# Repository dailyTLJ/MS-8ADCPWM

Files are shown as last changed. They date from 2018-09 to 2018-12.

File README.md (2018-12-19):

# MS_8ADCPWM

Board with 2x ADS8688a chips (8 analog inputs each) and 1x TLC5947 chip (24ch LED PWM driver).

Issues when chaining more than 4 boards (8 ADS8688a ics)

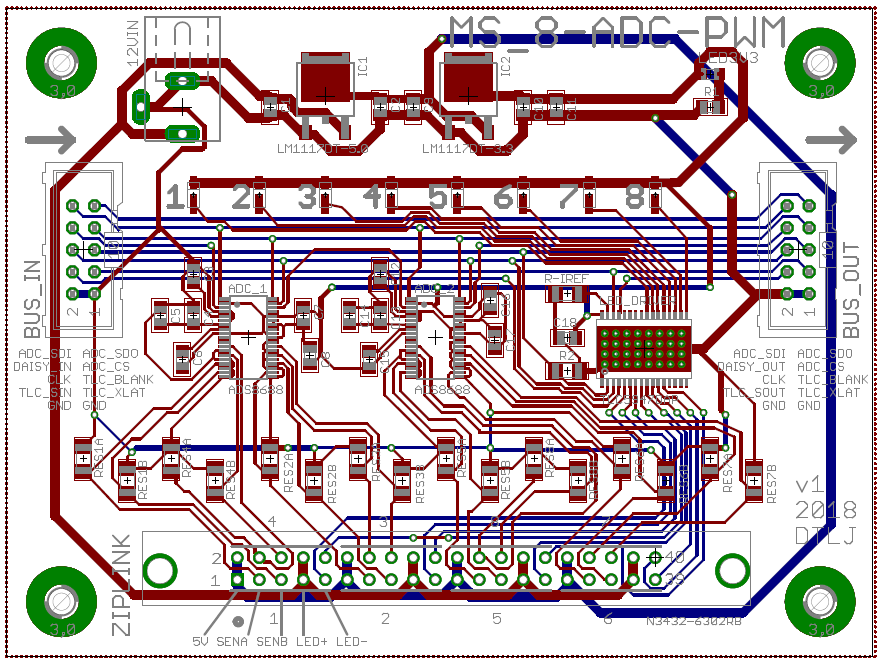
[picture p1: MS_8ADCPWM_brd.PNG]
Board


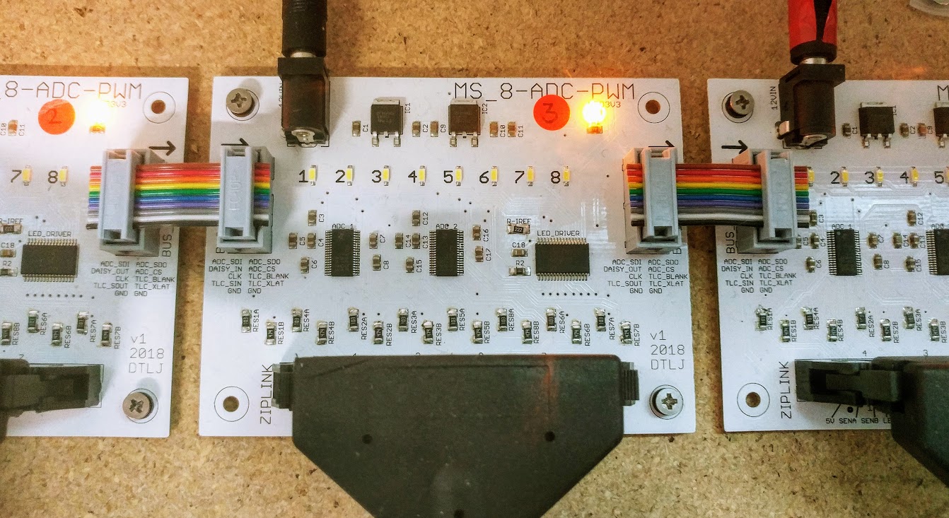
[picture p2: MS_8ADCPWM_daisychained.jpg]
In Action


## next iteration

* digital buffers, to allow larger chains
* default-off on LED channels, in the absence of control signal 
* power-in with screw terminals?

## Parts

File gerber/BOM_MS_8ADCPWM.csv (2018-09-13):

Designator | Manufacturer Part Number | Quantity
ADC_1, ADC_2 | ADS8688IDBT | 2
LED_DRIVER | TLC5947DAPR | 1
IC1 | LM1117IDTX-5.0/NOPB | 1
IC2 | LM1117IDTX-3.3/NOPB | 1
LED1B, LED2B, LED3B, LED4B, LED5B, LED6B, LED7B, LED8B | QBLP674-IWM-CW | 8
LED3V3 | LTST-C170EKT | 1
R1 | RC0805JR-07130RL | 1
R2 | RC0805FR-0710KL | 1
C9, C10, C18 | CL21F104ZBCNNNC | 3
C4, C6, C7, C13, C15, C16 | CL21B105KBFNNNE | 6
C1, C2, C3, C8, C12, C17 | CL21A106KPCLQNC | 6
C5, C11, C14 | CL21A226MQCLQNC | 3

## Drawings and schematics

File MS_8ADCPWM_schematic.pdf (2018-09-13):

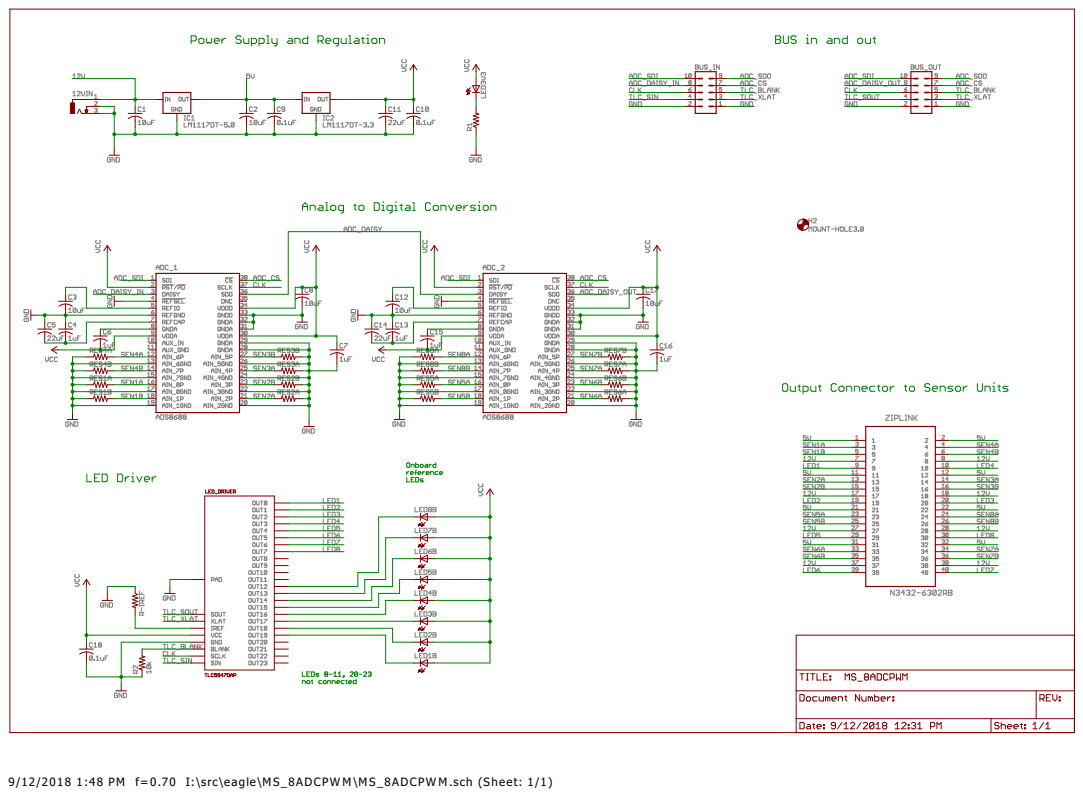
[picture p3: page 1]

9/12/2018 1:48 PM f=0.70 I:\src\eagle\MS_8ADCPW M\MS_8ADCPW M.sch (Sheet: 1/1)

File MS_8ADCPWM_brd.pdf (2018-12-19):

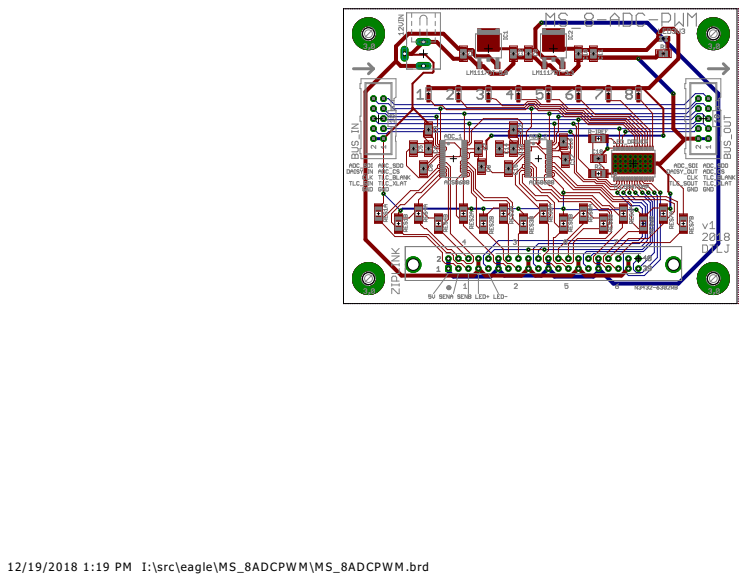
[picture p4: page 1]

12/19/2018 1:19 PM I:\src\eagle\MS_8ADCPW M\MS_8ADCPW M.brd

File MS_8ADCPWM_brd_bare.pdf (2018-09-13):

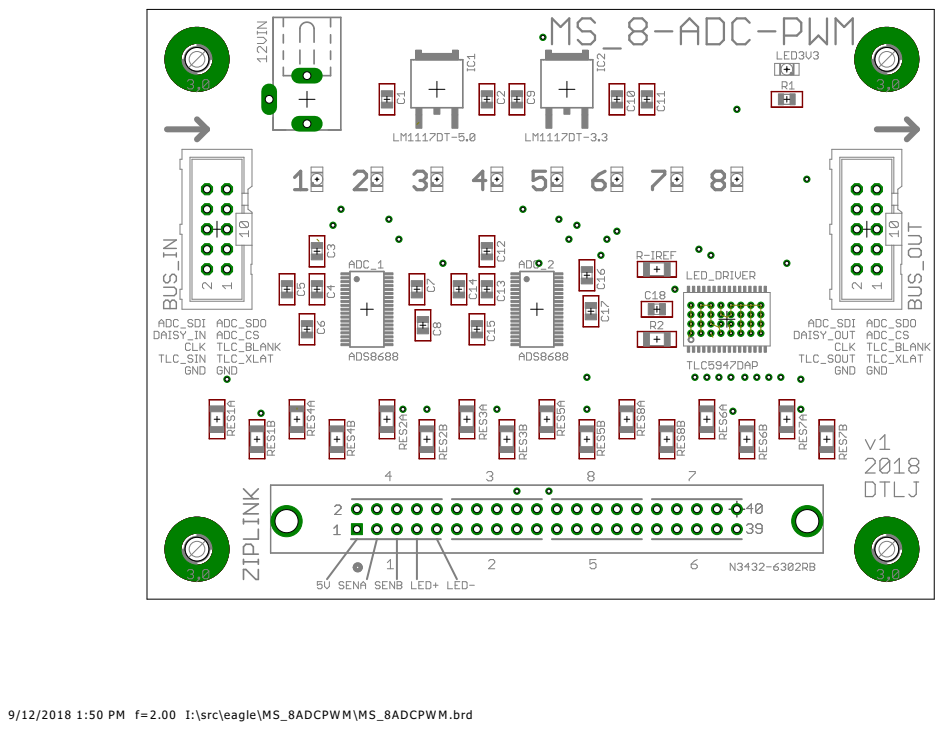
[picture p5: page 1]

9/12/2018 1:50 PM f=2.00 I:\src\eagle\MS_8ADCPW M\MS_8ADCPW M.brd

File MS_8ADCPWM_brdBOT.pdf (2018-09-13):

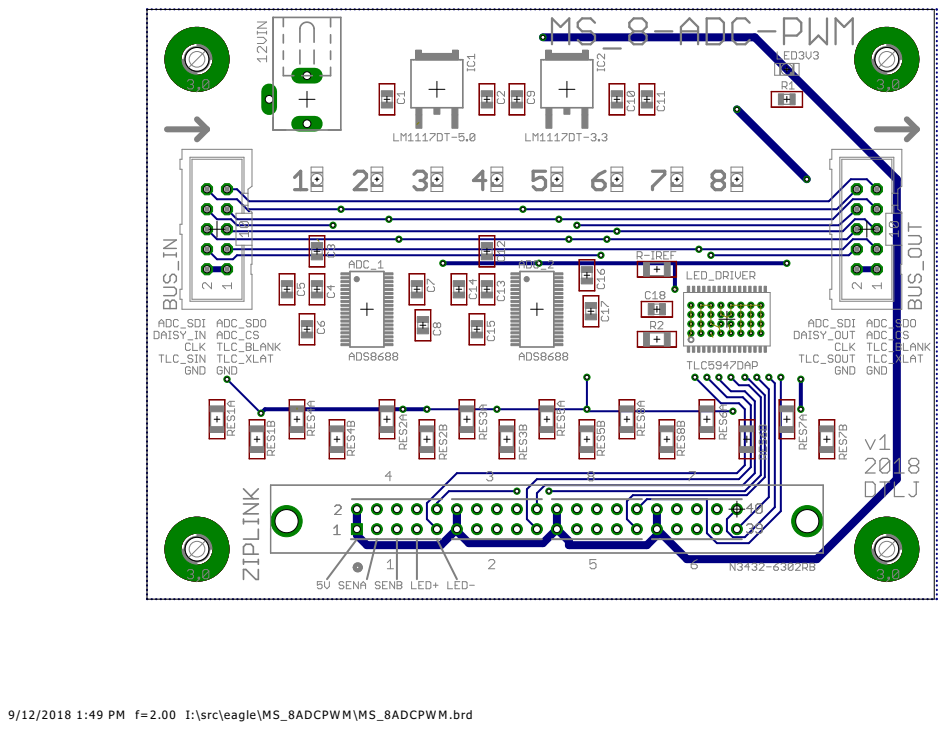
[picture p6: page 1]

9/12/2018 1:49 PM f=2.00 I:\src\eagle\MS_8ADCPW M\MS_8ADCPW M.brd

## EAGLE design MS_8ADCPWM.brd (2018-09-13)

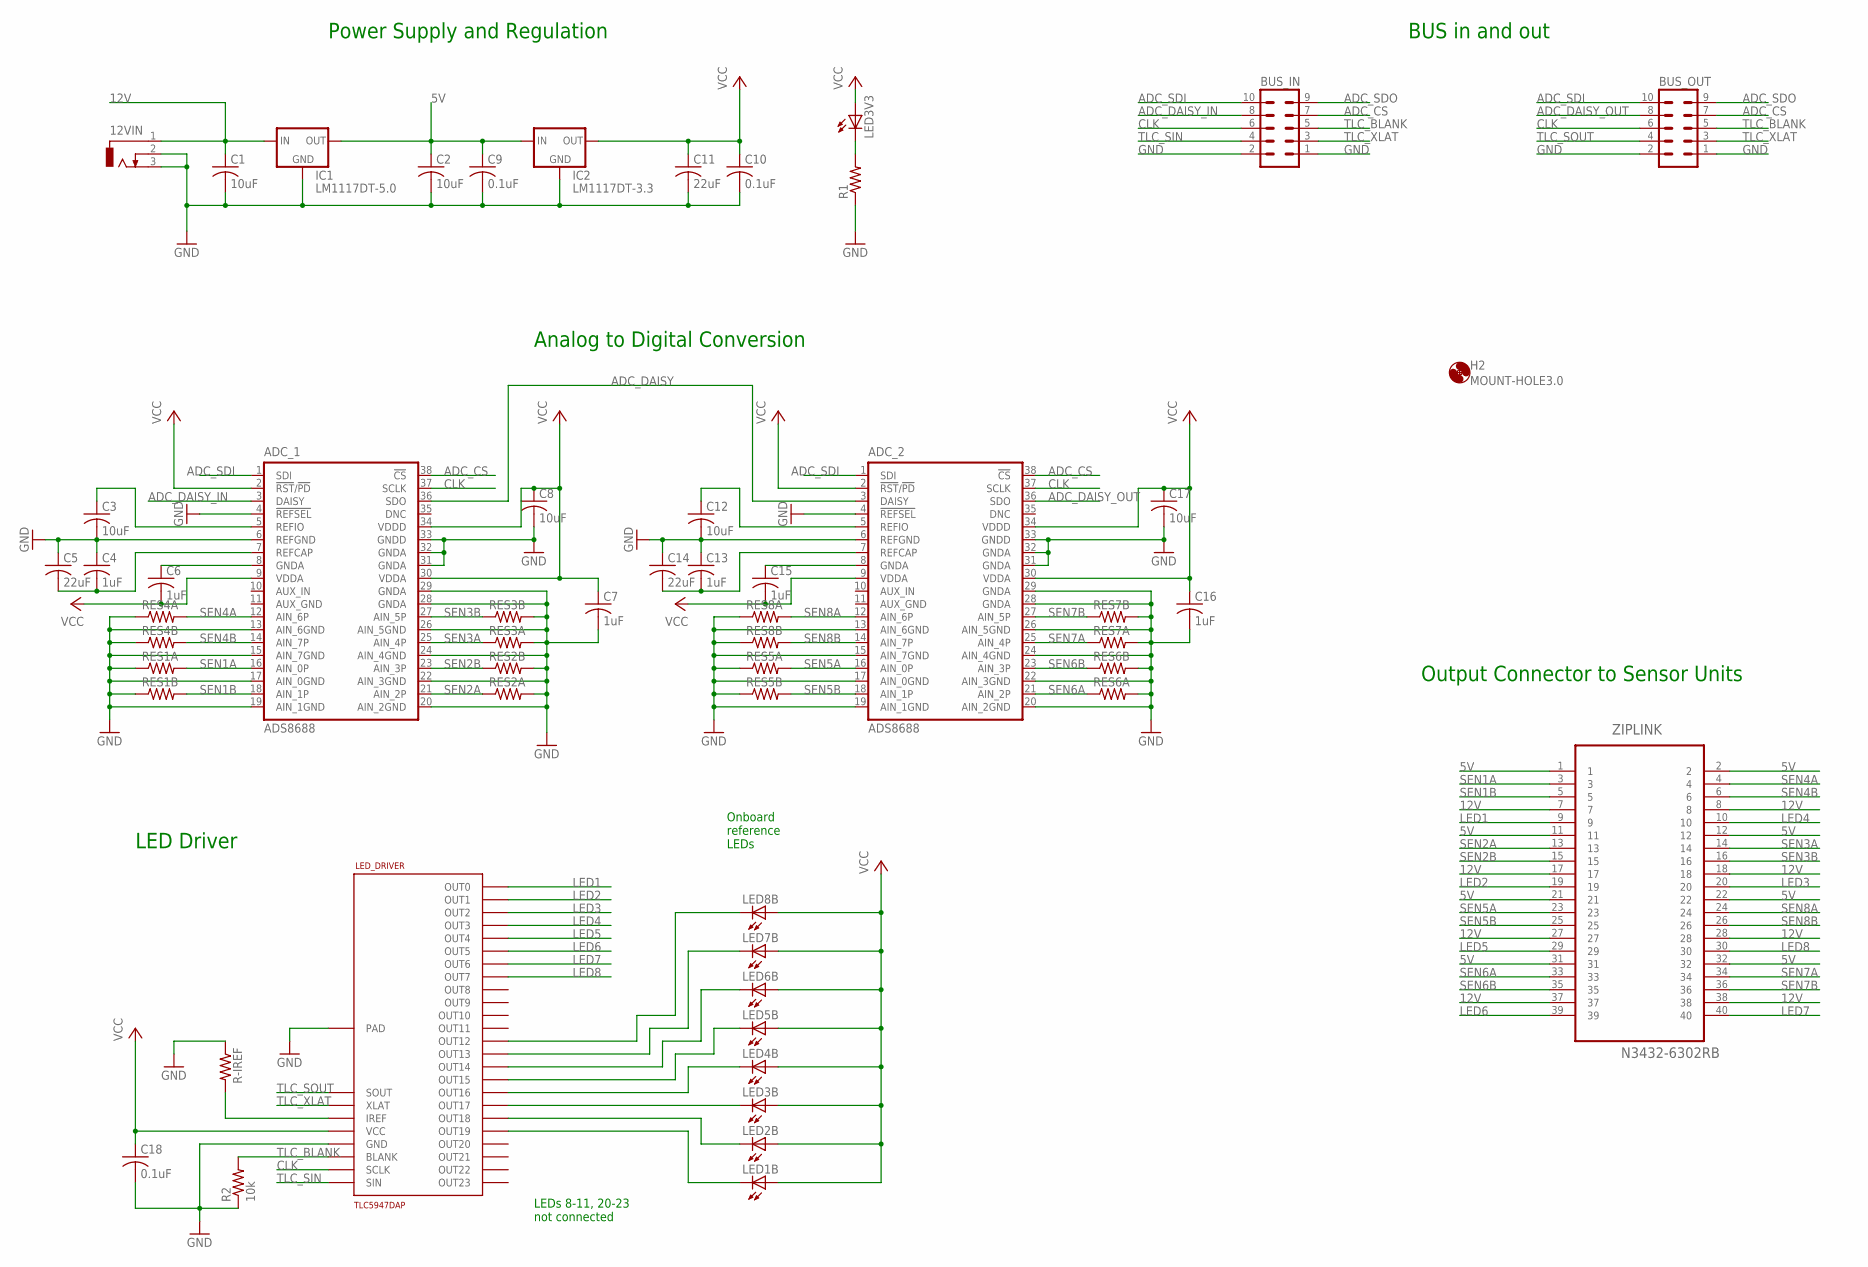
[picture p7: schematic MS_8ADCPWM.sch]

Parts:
12VIN: DCJ0303
ADC_1, ADC_2: ADS8688; DBT_R-PDSO-G38
BUS_IN: ML10
BUS_OUT: ML10
C1, C2, C3, C8, C12, C17: 10uF; C0805
C4, C6, C7, C13, C15, C16: 1uF; C0805
C5, C11, C14: 22uF; C0805
C9, C10, C18: 0.1uF; C0805
H2: MOUNT-HOLE3.0; 3,0
IC1: LM1117DT-5.0; TO252
IC2: LM1117DT-3.3; TO252
LED1B, LED2B, LED3B, LED4B, LED5B, LED6B, LED7B, LED8B: LEDSMD2PLCC; 2-PLCC
LED3V3: LEDCHIPLED_0805; CHIPLED_0805
LED_DRIVER: TLC5947DAP; HTSSOP32DAP
R1: R-US_R0805; R0805
R2: 10k; R1206
R-IREF: R-US_R1206; R1206
RES1A, RES1B, RES2A, RES2B, RES3A, RES3B, RES4A, RES4B, RES5A, RES5B, RES6A, RES6B, RES7A, RES7B, RES8A, RES8B: R-US_R1206; R1206
ZIPLINK: N3432-6302RB; 3M_N3432-6302RB

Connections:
5V: C2.1, C9.1, IC1.3 (OUT), IC2.2 (IN), ZIPLINK.1, ZIPLINK.2, ZIPLINK.11, ZIPLINK.12, ZIPLINK.21, ZIPLINK.22, ZIPLINK.31, ZIPLINK.32
12V: 12VIN.1, C1.1, IC1.2 (IN), ZIPLINK.7, ZIPLINK.8, ZIPLINK.17, ZIPLINK.18, ZIPLINK.27, ZIPLINK.28, ZIPLINK.37, ZIPLINK.38
ADC_CS: ADC_1.38 (!CS), ADC_2.38 (!CS), BUS_IN.7, BUS_OUT.7
ADC_DAISY: ADC_1.36 (SDO), ADC_2.3 (DAISY)
ADC_DAISY_IN: ADC_1.3 (DAISY), BUS_IN.8
ADC_DAISY_OUT: ADC_2.36 (SDO), BUS_OUT.8
ADC_SDI: ADC_1.1 (SDI), ADC_2.1 (SDI), BUS_IN.10, BUS_OUT.10
ADC_SDO: BUS_IN.9, BUS_OUT.9
CLK: ADC_1.37 (SCLK), ADC_2.37 (SCLK), BUS_IN.6, BUS_OUT.6, LED_DRIVER.3 (SCLK)
GND: 12VIN.2, 12VIN.3, ADC_1.4 (!REFSEL), ADC_1.6 (REFGND), ADC_1.13 (AIN_6GND), ADC_1.15 (AIN_7GND), ADC_1.17 (AIN_0GND), ADC_1.19 (AIN_1GND), ADC_1.20 (AIN_2GND), ADC_1.22 (AIN_3GND), ADC_1.24 (AIN_4GND), ADC_1.26 (AIN_5GND), ADC_1.28 (GNDA), ADC_1.29 (GNDA), ADC_1.31 (GNDA), ADC_1.32 (GNDA), ADC_1.33 (GNDD), ADC_2.4 (!REFSEL), ADC_2.6 (REFGND), ADC_2.13 (AIN_6GND), ADC_2.15 (AIN_7GND), ADC_2.17 (AIN_0GND), ADC_2.19 (AIN_1GND), ADC_2.20 (AIN_2GND), ADC_2.22 (AIN_3GND), ADC_2.24 (AIN_4GND), ADC_2.26 (AIN_5GND), ADC_2.28 (GNDA), ADC_2.29 (GNDA), ADC_2.31 (GNDA), ADC_2.32 (GNDA), ADC_2.33 (GNDD), BUS_IN.1, BUS_IN.2, BUS_OUT.1, BUS_OUT.2, C1.2, C2.2, C3.2, C4.1, C5.1, C7.2, C8.2, C9.2, C10.2, C11.2, C12.2, C13.1, C14.1, C16.2, C17.2, C18.2, IC1.1 (GND), IC2.1 (GND), LED_DRIVER.1 (GND), LED_DRIVER.EXP (PAD), R1.1, R2.1, R-IREF.1, RES1A.1, RES1B.1, RES2A.2, RES2B.2, RES3A.2, RES3B.2, RES4A.1, RES4B.1, RES5A.1, RES5B.1, RES6A.2, RES6B.2, RES7A.2, RES7B.2, RES8A.1, RES8B.1
LED1: LED_DRIVER.5 (OUT0), ZIPLINK.9
LED2: LED_DRIVER.6 (OUT1), ZIPLINK.19
LED3: LED_DRIVER.7 (OUT2), ZIPLINK.20
LED4: LED_DRIVER.8 (OUT3), ZIPLINK.10
LED5: LED_DRIVER.9 (OUT4), ZIPLINK.29
LED6: LED_DRIVER.10 (OUT5), ZIPLINK.39
LED7: LED_DRIVER.11 (OUT6), ZIPLINK.40
LED8: LED_DRIVER.12 (OUT7), ZIPLINK.30
unnamed: ADC_1.5 (REFIO), C3.1
unnamed: LED3V3.C, R1.2
unnamed: ADC_2.7 (REFCAP), C13.2, C14.2
unnamed: ADC_1.7 (REFCAP), C4.2, C5.2
unnamed: ADC_2.5 (REFIO), C12.1
unnamed: ADC_2.8 (GNDA), C15.1
unnamed: ADC_1.8 (GNDA), C6.1
unnamed: LED1B.C, LED_DRIVER.24 (OUT19)
unnamed: LED_DRIVER.31 (IREF), R-IREF.2
unnamed: LED2B.C, LED_DRIVER.23 (OUT18)
unnamed: LED3B.C, LED_DRIVER.22 (OUT17)
unnamed: LED4B.C, LED_DRIVER.21 (OUT16)
unnamed: LED5B.C, LED_DRIVER.20 (OUT15)
unnamed: LED6B.C, LED_DRIVER.19 (OUT14)
unnamed: LED7B.C, LED_DRIVER.18 (OUT13)
unnamed: LED8B.C, LED_DRIVER.17 (OUT12)
SEN1A: ADC_1.16 (AIN_0P), RES1A.2, ZIPLINK.3
SEN1B: ADC_1.18 (AIN_1P), RES1B.2, ZIPLINK.5
SEN2A: ADC_1.21 (AIN_2P), RES2A.1, ZIPLINK.13
SEN2B: ADC_1.23 (AIN_3P), RES2B.1, ZIPLINK.15
SEN3A: ADC_1.25 (AIN_4P), RES3A.1, ZIPLINK.14
SEN3B: ADC_1.27 (AIN_5P), RES3B.1, ZIPLINK.16
SEN4A: ADC_1.12 (AIN_6P), RES4A.2, ZIPLINK.4
SEN4B: ADC_1.14 (AIN_7P), RES4B.2, ZIPLINK.6
SEN5A: ADC_2.16 (AIN_0P), RES5A.2, ZIPLINK.23
SEN5B: ADC_2.18 (AIN_1P), RES5B.2, ZIPLINK.25
SEN6A: ADC_2.21 (AIN_2P), RES6A.1, ZIPLINK.33
SEN6B: ADC_2.23 (AIN_3P), RES6B.1, ZIPLINK.35
SEN7A: ADC_2.25 (AIN_4P), RES7A.1, ZIPLINK.34
SEN7B: ADC_2.27 (AIN_5P), RES7B.1, ZIPLINK.36
SEN8A: ADC_2.12 (AIN_6P), RES8A.2, ZIPLINK.24
SEN8B: ADC_2.14 (AIN_7P), RES8B.2, ZIPLINK.26
TLC_BLANK: BUS_IN.5, BUS_OUT.5, LED_DRIVER.2 (BLANK), R2.2
TLC_SIN: BUS_IN.4, LED_DRIVER.4 (SIN)
TLC_SOUT: BUS_OUT.4, LED_DRIVER.29 (SOUT)
TLC_XLAT: BUS_IN.3, BUS_OUT.3, LED_DRIVER.30 (XLAT)
VCC: ADC_1.2 (!RST!/!PD), ADC_1.9 (VDDA), ADC_1.30 (VDDA), ADC_1.34 (VDDD), ADC_2.2 (!RST!/!PD), ADC_2.9 (VDDA), ADC_2.30 (VDDA), ADC_2.34 (VDDD), C6.2, C7.1, C8.1, C10.1, C11.1, C15.2, C16.1, C17.1, C18.1, IC2.3 (OUT), LED1B.A, LED2B.A, LED3B.A, LED3V3.A, LED4B.A, LED5B.A, LED6B.A, LED7B.A, LED8B.A, LED_DRIVER.32 (VCC)

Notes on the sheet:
Power Supply and Regulation
Analog to Digital Conversion
LED Driver
Output Connector to Sensor Units
BUS in and out
Onboard reference LEDs
LEDs 8-11, 20-23 not connected

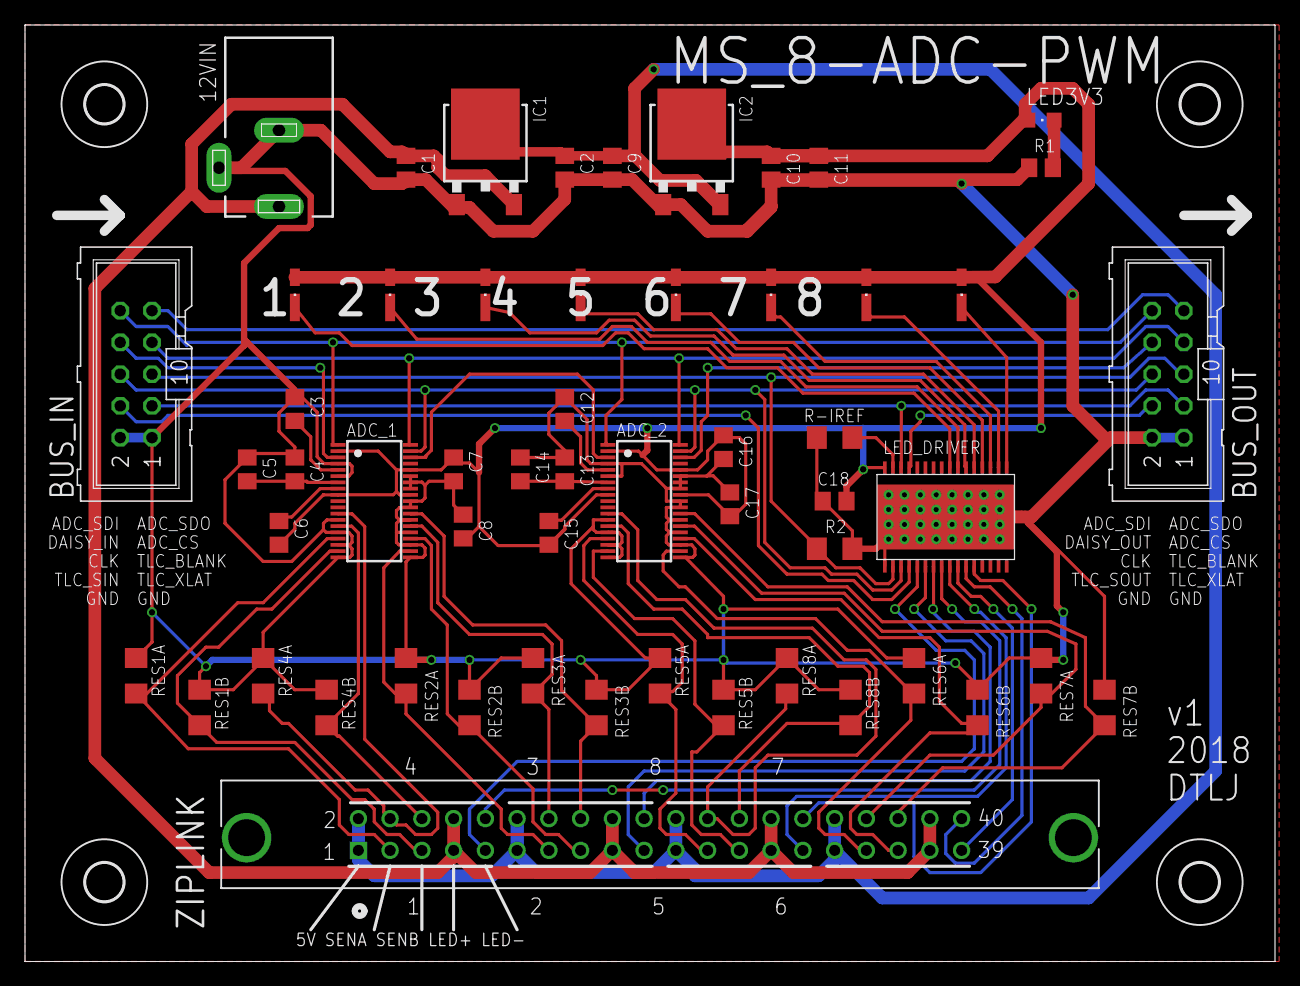
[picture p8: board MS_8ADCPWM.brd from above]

Board: 2 copper layers, 100.0 x 74.9 mm, 59 parts (0 on the bottom side), 55 nets.

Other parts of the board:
H1, H3, H4: MOUNT-HOLE3.0; 3,0

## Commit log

2018-09-13 ready for 1st production
    [BOM_MS_8ADCPWM.csv, BOM_MS_8ADCPWM_slim.csv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]
2018-12-19 add images
    [BOM_MS_8ADCPWM_slim.csv]
